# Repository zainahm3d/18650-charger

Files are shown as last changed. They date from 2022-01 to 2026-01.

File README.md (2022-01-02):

# 18650-charger
Dual channel USB-C LiFeP04 18650 charger based on 2x LTC4121 with two independant channels. Fully charged voltage is set to 3.6V at a current of 400mA.

## Images
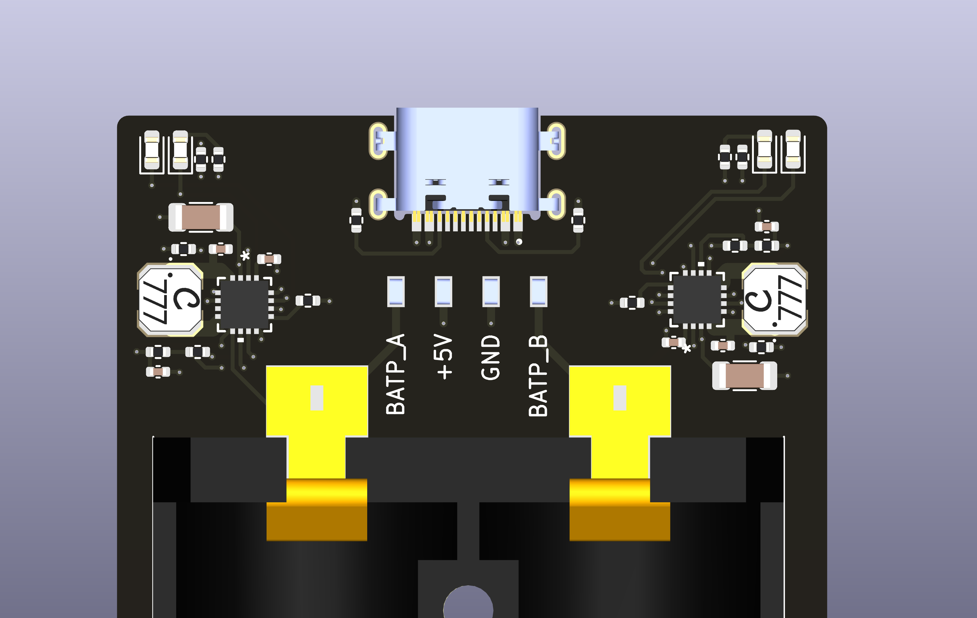
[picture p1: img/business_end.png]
Business end

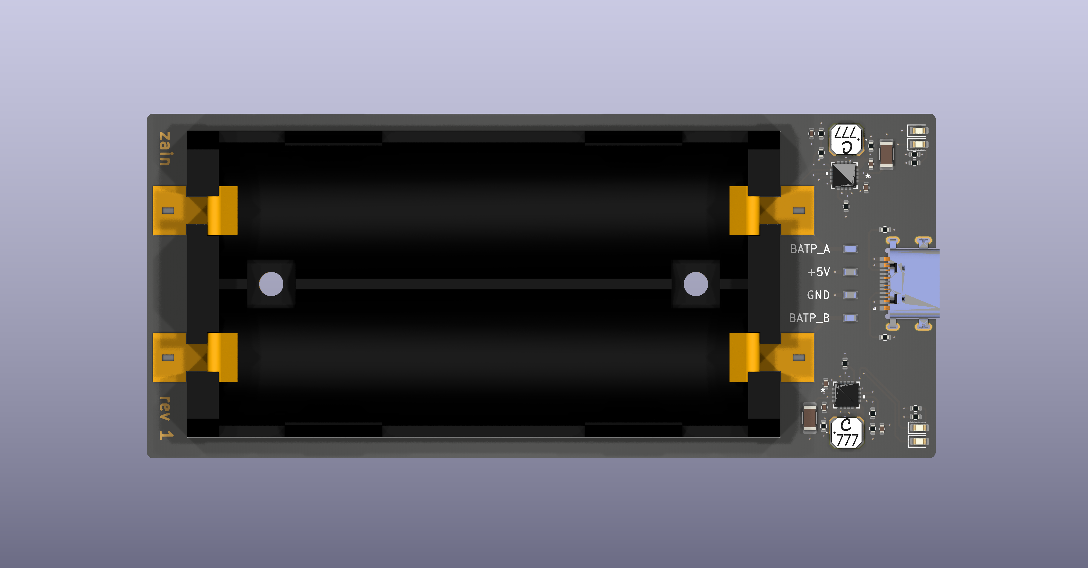
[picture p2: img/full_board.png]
Full board


## Test results from charging two cells
Capture from a Saleae logic analyzer. See the data file [here](doc/chargetest.sal)
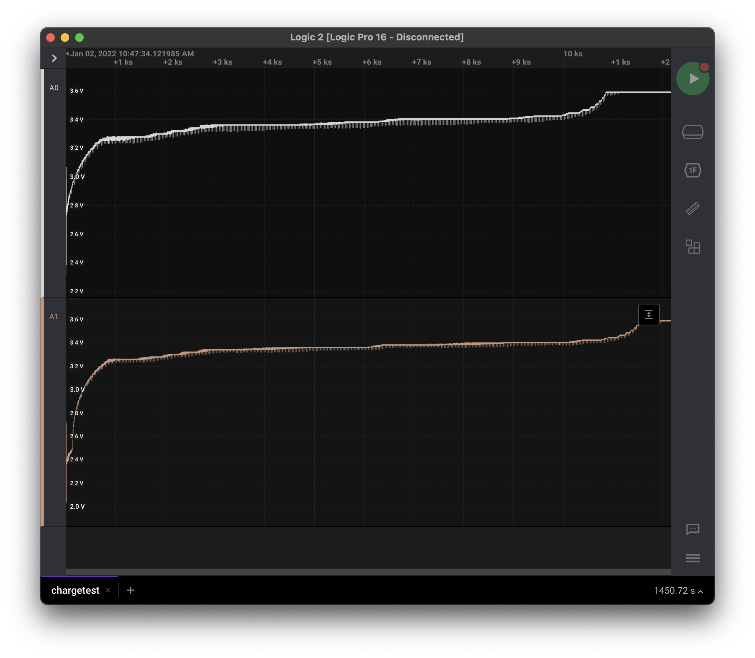
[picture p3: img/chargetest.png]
Saleae Logic capture


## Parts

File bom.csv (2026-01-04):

Id | Designator | Package | Quantity | Designation | Digikey PN
1 | TP2,TP3,TP1,TP4 | TP+195X110 | 4 | TestPoint | A106145CT-ND
2 | J1 | GCT_USB4505-03-0-A_REVA | 1 | USB4505-03-0-A_REVA | 2073-USB4505-03-0-ACT-ND
3 | R7,R8,R13,R14 | R_0402_1005Metric | 4 | 600 | 541-RCS0402604RFKEDCT-ND
4 | R5,R11 | R_0402_1005Metric | 2 | 887K | YAG3251CT-ND
5 | C5,C1 | C_1206_3216Metric | 2 | 10uF | 490-6518-1-ND
6 | L5,L2 | LED_0603_1608Metric | 2 | GRN | 732-12017-1-ND
7 | R1,R2 | R_0402_1005Metric | 2 | 5.1K | YAG1457CT-ND
8 | R4,R10 | R_0402_1005Metric | 2 | 10K | 13-AA0402FR-0710KLCT-ND
9 | L6,L3 | INDP_LPS4018-473MRB | 2 | 47uH | 2457-LPS4018-473MRC-ND
10 | C7,C3 | C_0402_1005Metric | 2 | 22uF | 1276-7090-1-ND
11 | C4,C8 | C_0402_1005Metric | 2 | 2.2uF | 490-12267-1-ND
12 | L4,L1 | LED_0603_1608Metric | 2 | RED | 732-12016-1-ND
13 | U1,U2 | QFN-16_UD | 2 | LTC4121IUDTRPBF | LTC4121EUD#PBF-ND
14 | C6,C2 | C_0402_1005Metric | 2 | 22nF | 399-17166-1-ND
15 | R9,R3 | R_0402_1005Metric | 2 | 3.01K | 13-RT0402FRE073KLCT-ND
16 | R12,R6 | R_0402_1005Metric | 2 | 1780K | 13-RC0402FR-071M78LCT-ND
17 | BT1 | BAT_1048 | 1 | 1048 | 36-1048-ND
18 | U3 | SOT-363_SC-70-6 | 1 | LM66100DCK | 296-53541-1-ND
19 | C9 | C_0402_1005Metric | 1 | 1uF | 399-12288-1-ND

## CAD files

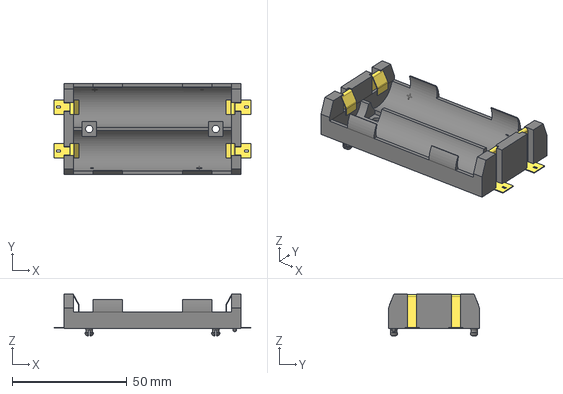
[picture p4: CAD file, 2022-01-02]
components/1048/Keystone_-_1048.step
86.0 x 39.8 x 18.3 mm

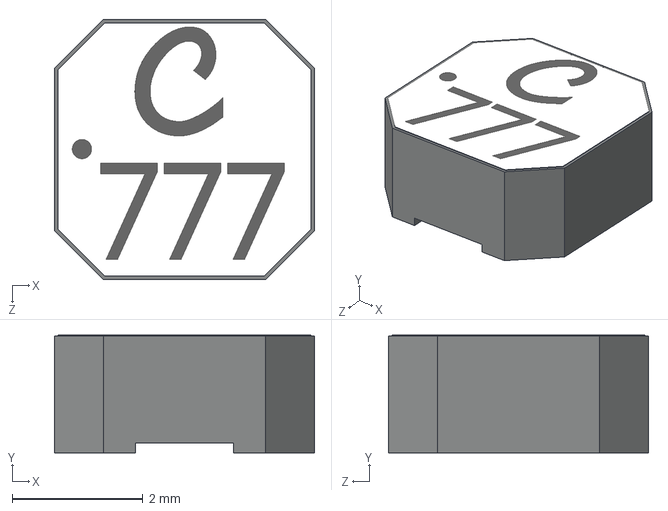
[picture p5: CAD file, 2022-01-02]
components/LPS4018-472MRB/Coilcraft-LPS4018.step
3.98 x 1.80 x 3.98 mm

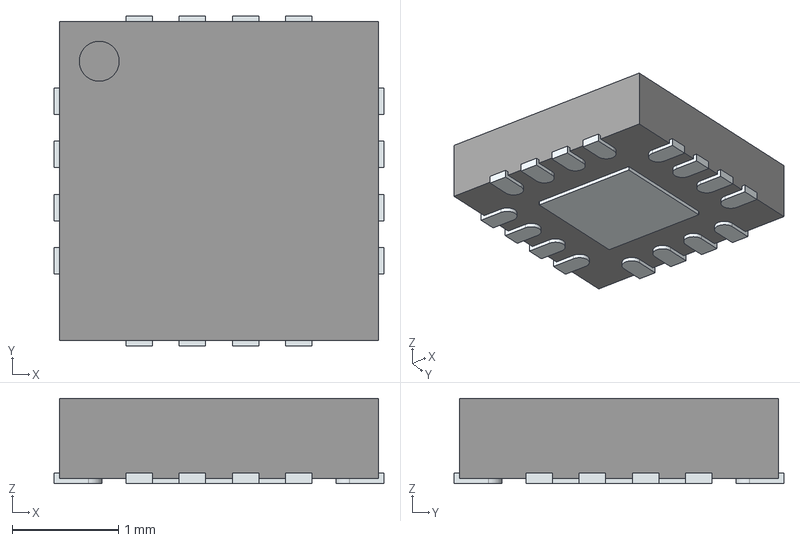
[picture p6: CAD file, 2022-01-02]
components/LTC4121IUDTRPBF/LTC4121.stp
3.10 x 3.10 x 0.8 mm
ThermalPin
PinsArrayLR
PinsArrayTB

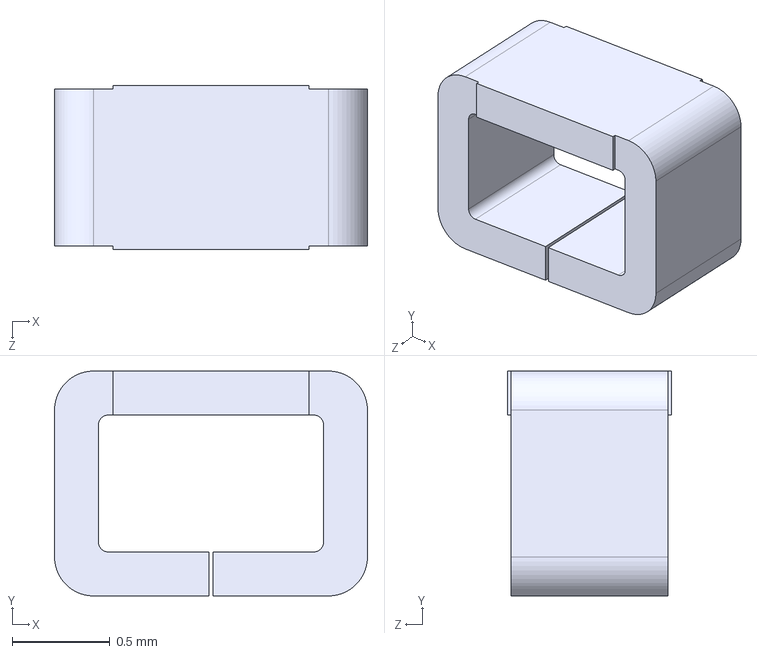
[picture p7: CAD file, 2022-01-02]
components/RCU-0C/RCU-0C.step
1.60 x 1.15 x 0.84 mm

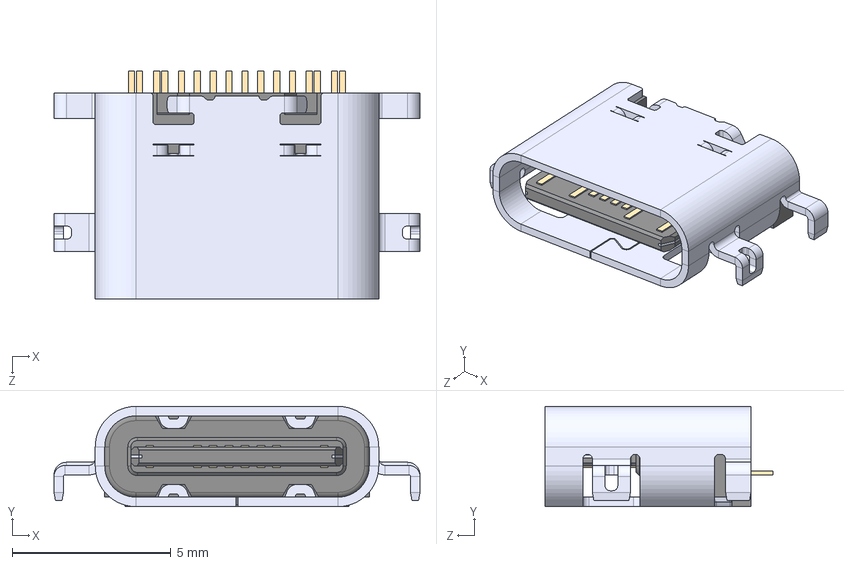
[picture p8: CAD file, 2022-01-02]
components/USB4505-03-0-A_REVA/USB4505-03-0-A_REVA.step
11.5 x 3.16 x 7.20 mm

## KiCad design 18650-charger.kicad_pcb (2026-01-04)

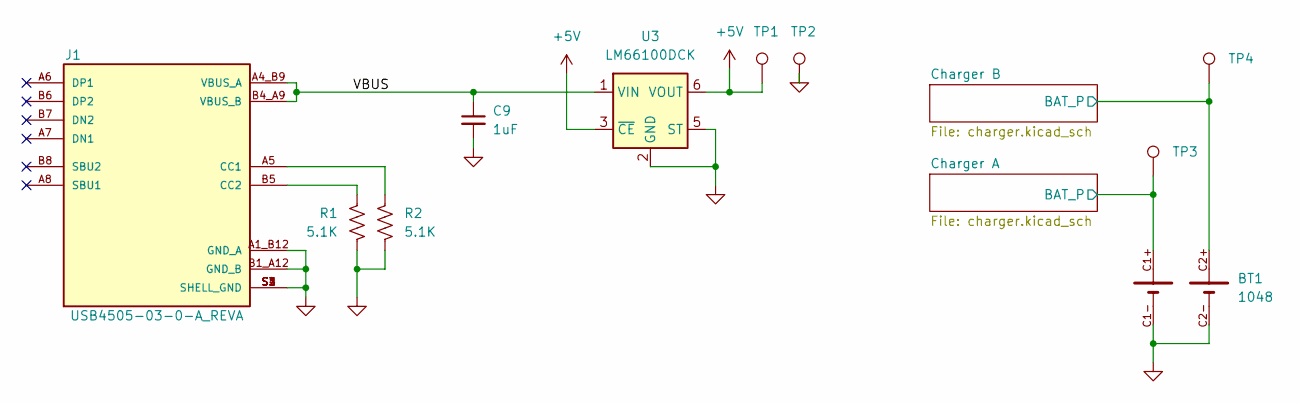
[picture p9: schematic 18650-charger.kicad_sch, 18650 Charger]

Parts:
BT1: 1048; BAT_1048
C9: 1uF; C_0402_1005Metric
J1: USB4505-03-0-A_REVA; GCT_USB4505-03-0-A_REVA; PARTREV A
R1, R2: 5.1K; R_0402_1005Metric
TP1, TP2, TP3, TP4: TestPoint; TP+195X110
U3: LM66100DCK; SOT-363_SC-70-6

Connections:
+5V: TP1.1, U3.3 (~CE), U3.6 (VOUT); also elsewhere on the board
/Charger A/BAT_P: BT1.C1+, TP3.1; also elsewhere on the board
/Charger B/BAT_P: BT1.C2+, TP4.1; also elsewhere on the board
/VBUS: C9.1, J1.A4_B9 (VBUS_A), J1.B4_A9 (VBUS_B), U3.1 (VIN)
GND: BT1.C1-, BT1.C2-, C9.2, J1.A1_B12 (GND_A), J1.B1_A12 (GND_B), J1.S1 (SHELL_GND), J1.S2 (SHELL_GND), J1.S3 (SHELL_GND), J1.S4 (SHELL_GND), R1.1, R2.2, TP2.1, U3.2 (GND), U3.5 (ST); also elsewhere on the board
unnamed: J1.A5 (CC1), R2.1
unnamed: J1.B5 (CC2), R1.2

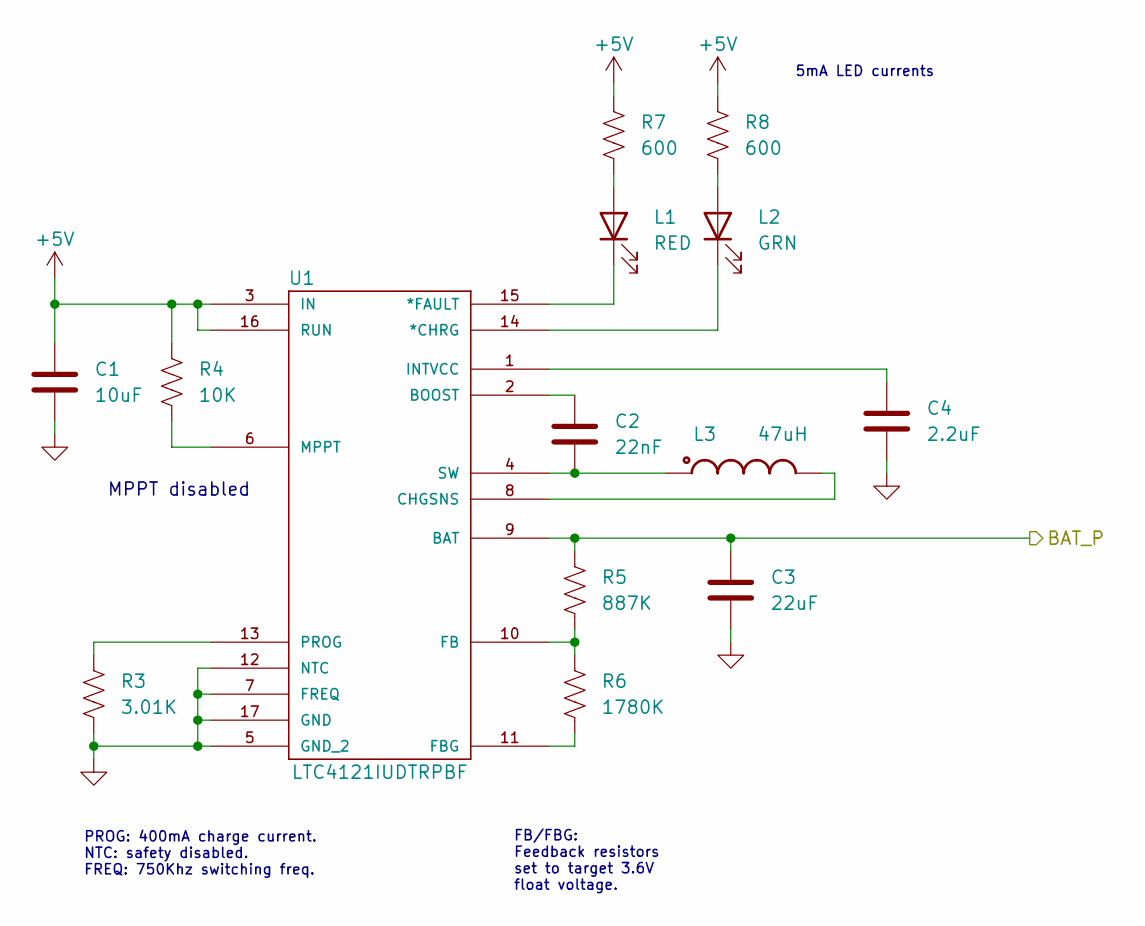
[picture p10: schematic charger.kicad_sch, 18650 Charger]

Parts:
C1: 10uF; C_1206_3216Metric
C2: 22nF; C_0402_1005Metric
C3: 22uF; C_0402_1005Metric
C4: 2.2uF; C_0402_1005Metric
L1: RED; LED_0603_1608Metric
L2: GRN; LED_0603_1608Metric
L3: 47uH; INDP_LPS4018-472MRB
R3: 3.01K; R_0402_1005Metric
R4: 10K; R_0402_1005Metric
R5: 887K; R_0402_1005Metric
R6: 1780K; R_0402_1005Metric
R7, R8: 600; R_0402_1005Metric
U1: LTC4121IUDTRPBF; QFN-16_UD; MANUFACTURER_PART_NUMBER ltc4121iud#trpbf

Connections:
+5V: C1.1, R4.1, R7.1, R8.1, U1.3 (IN), U1.16 (RUN); also elsewhere on the board
/Charger A/BAT_P: C3.1, R5.1, U1.9 (BAT); also elsewhere on the board
GND: C1.2, C3.2, C4.2, R3.1, U1.5 (GND_2), U1.7 (FREQ), U1.12 (NTC), U1.17 (GND); also elsewhere on the board
unnamed: L1.2 (A), R7.2
unnamed: L1.1 (K), U1.15 (*FAULT)
unnamed: L2.2 (A), R8.2
unnamed: L2.1 (K), U1.14 (*CHRG)
unnamed: C2.1, U1.2 (BOOST)
unnamed: L3.2, U1.8 (CHGSNS)
unnamed: R5.2, R6.1, U1.10 (FB)
unnamed: R6.2, U1.11 (FBG)
unnamed: C4.1, U1.1 (INTVCC)
unnamed: R4.2, U1.6 (MPPT)
unnamed: R3.2, U1.13 (PROG)
unnamed: C2.2, L3.1, U1.4 (SW)

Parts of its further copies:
C5: 10uF; C_1206_3216Metric
C6: 22nF; C_0402_1005Metric
C7: 22uF; C_0402_1005Metric
C8: 2.2uF; C_0402_1005Metric
L4: RED; LED_0603_1608Metric
L5: GRN; LED_0603_1608Metric
L6: 47uH; INDP_LPS4018-472MRB
R9: 3.01K; R_0402_1005Metric
R10: 10K; R_0402_1005Metric
R11: 887K; R_0402_1005Metric
R12: 1780K; R_0402_1005Metric
R13, R14: 600; R_0402_1005Metric
U2: LTC4121IUDTRPBF; QFN-16_UD; MANUFACTURER_PART_NUMBER ltc4121iud#trpbf

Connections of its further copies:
+5V: C5.1, R10.1, R13.1, R14.1, U2.3 (IN), U2.16 (RUN); also elsewhere on the board
/Charger B/BAT_P: C7.1, R11.1, U2.9 (BAT); also elsewhere on the board
GND: C5.2, C7.2, C8.2, R9.1, U2.5 (GND_2), U2.7 (FREQ), U2.12 (NTC), U2.17 (GND); also elsewhere on the board
unnamed: L4.2 (A), R13.2
unnamed: L4.1 (K), U2.15 (*FAULT)
unnamed: L5.2 (A), R14.2
unnamed: L5.1 (K), U2.14 (*CHRG)
unnamed: C6.1, U2.2 (BOOST)
unnamed: L6.2, U2.8 (CHGSNS)
unnamed: R11.2, R12.1, U2.10 (FB)
unnamed: R12.2, U2.11 (FBG)
unnamed: C8.1, U2.1 (INTVCC)
unnamed: R10.2, U2.6 (MPPT)
unnamed: R9.2, U2.13 (PROG)
unnamed: C6.2, L6.1, U2.4 (SW)

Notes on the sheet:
PROG: 400mA charge current. NTC: safety disabled. FREQ: 750Khz switching freq.
5mA LED currents
FB/FBG: Feedback resistors set to target 3.6V float voltage.
MPPT disabled

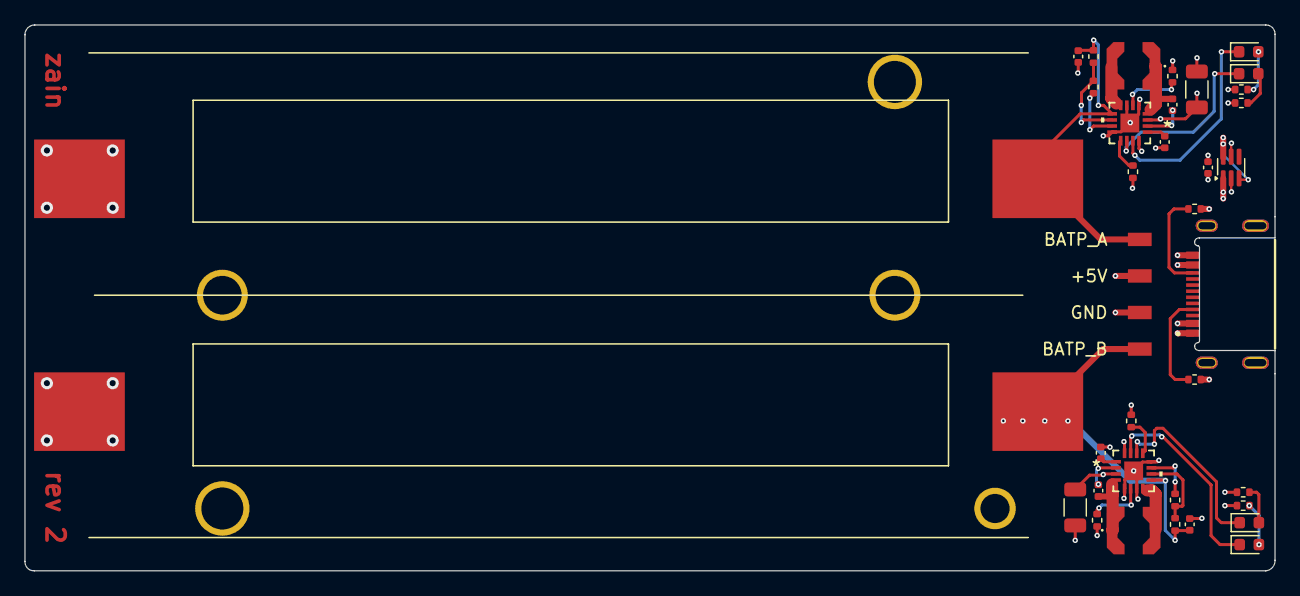
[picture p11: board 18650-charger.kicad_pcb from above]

Board: 4 copper layers, 102.6 x 44.8 mm, 38 parts (0 on the bottom side), 31 nets.

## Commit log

2022-01-02 Version 1
    [18650-charger.kicad_pcb, 18650-charger.kicad_sch, Coilcraft-LPS4018.step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]
2026-01-04 Rev 2, add ideal diode
    [18650-charger.kicad_pcb, 18650-charger.kicad_sch, bom.csv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]
